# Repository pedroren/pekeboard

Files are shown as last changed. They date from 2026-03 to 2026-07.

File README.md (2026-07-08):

# PeKeboard
PeKeboard and PeKepad

## Idea
The idea was to create a split keyboard without losing some of the occasional keys for miscellaneous or occasional use, like the Function, Media keys and Arrow keys.

I took inspiration (and was about to build) on the Apiaster keyboard (https://github.com/nmunnich/apiaster) and the Soffle variant Souffle (https://github.com/climent/SouffleKeyboard).

So I decided to create a three part keyboard, composed of a pair of split sides, left and right; and a central Macropad, containing the Function and Arrows keys, and a pair of rotary encoders. This central/macropad also doubles as the Dongle, containing a display to show layer and peripherals battery information.

## Tools
- Ergogen
- Kicad
- freerouting

## Folders structure
- layout_keymap:
- pekeboard
- pekepad
- pekepad-v
- zmk-firmware
- rmk_firmware
- release
- kicad

## Subfolders
- cases
- footprints
- pcbs

## Build guide
see build_guide.md

## Todo

## Referenced libraries

- ZMK
- zmk-dongle-display (https://github.com/englmaxi/zmk-dongle-display)
- zmk-feature-status-led (https://github.com/sekigon-gonnoc/zmk-feature-status-led)

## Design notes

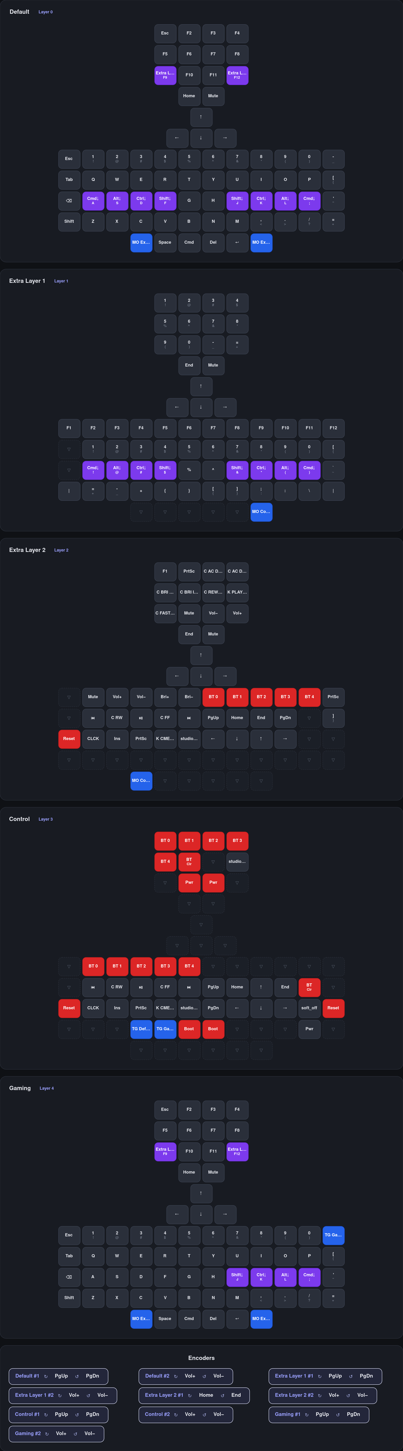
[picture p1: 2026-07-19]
layout_keymap/trio-keymap.png

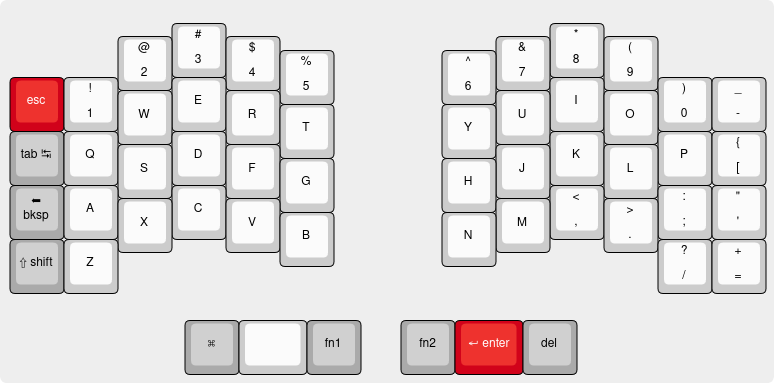
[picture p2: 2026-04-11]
layout_keymap/pekeboard-keyboard-editor-keymap-draft.png

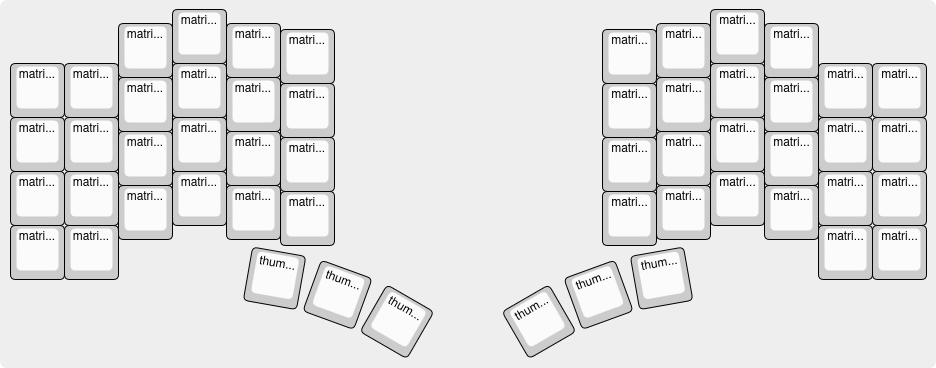
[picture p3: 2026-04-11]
layout_keymap/pekeboard-keyboard-editor-physical.png

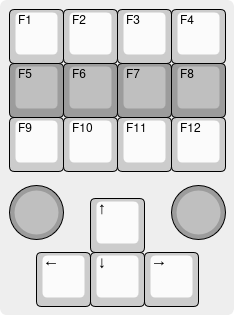
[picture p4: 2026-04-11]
layout_keymap/pekepadv-layout.png

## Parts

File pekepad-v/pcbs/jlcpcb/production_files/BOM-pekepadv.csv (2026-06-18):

Comment | Designator | Footprint | LCSC | Quantity
 | D1,D10,D11,D12,D13,D14,D15,D16,D17,D18,D2,D3,D4,D5,D6,D7,D8,D9 | diode_tht_sod123 | C7420318 | 18

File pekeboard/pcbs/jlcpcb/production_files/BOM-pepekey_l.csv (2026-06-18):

Comment | Designator | Footprint | LCSC | Quantity
 | D1,D10,D11,D12,D13,D14,D15,D16,D17,D18,D19,D2,D20,D21,D22,D23,D24,D25,D26,D27,D3,D4,D5,D6,D7,D8,D9 | diode_tht_sod123 | C7420318 | 27

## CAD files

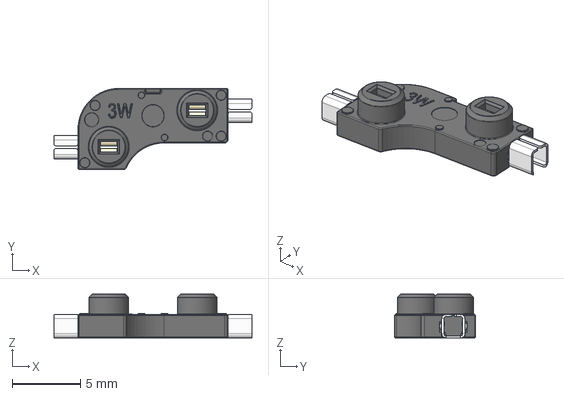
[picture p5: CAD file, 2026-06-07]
kicad/3dmodels/SW_Hotswap_Kailh_MX.stp
14.5 x 5.95 x 3.22 mm

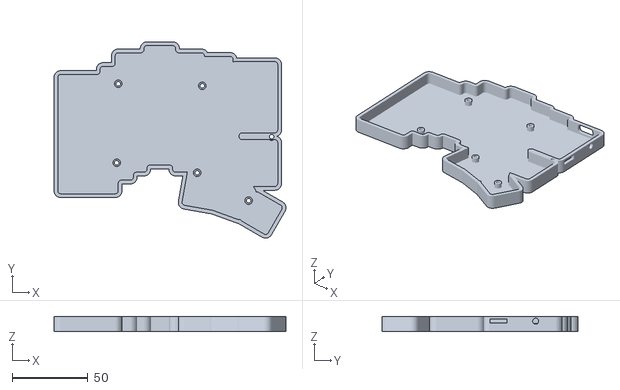
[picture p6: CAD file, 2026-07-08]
pekeboard/cases/case.stl
153.5 x 129.9 x 9.70

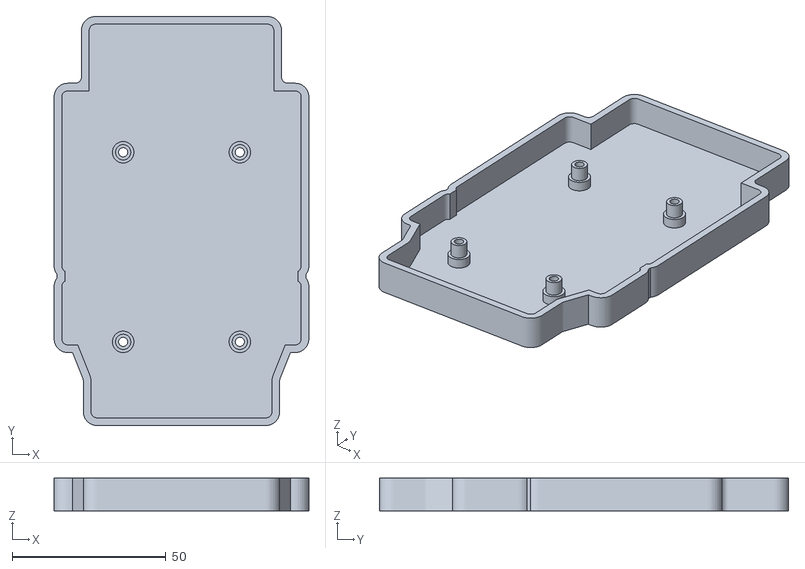
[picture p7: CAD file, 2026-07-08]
pekepad-v/cases/case.stl
83.0 x 133.2 x 10.7

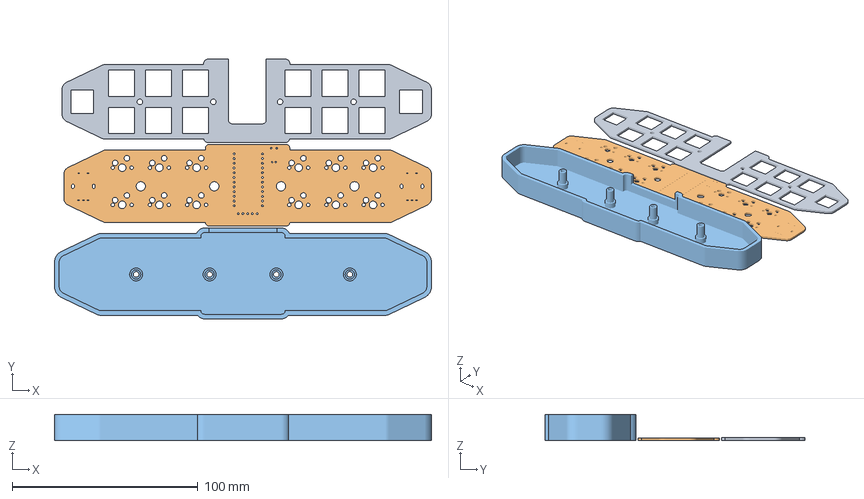
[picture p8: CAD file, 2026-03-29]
pekepad/cases/cases.3mf
202.7 x 139.7 x 14.2 mm
switch_plate.stl
pekepad_pcb.stl
case.stl

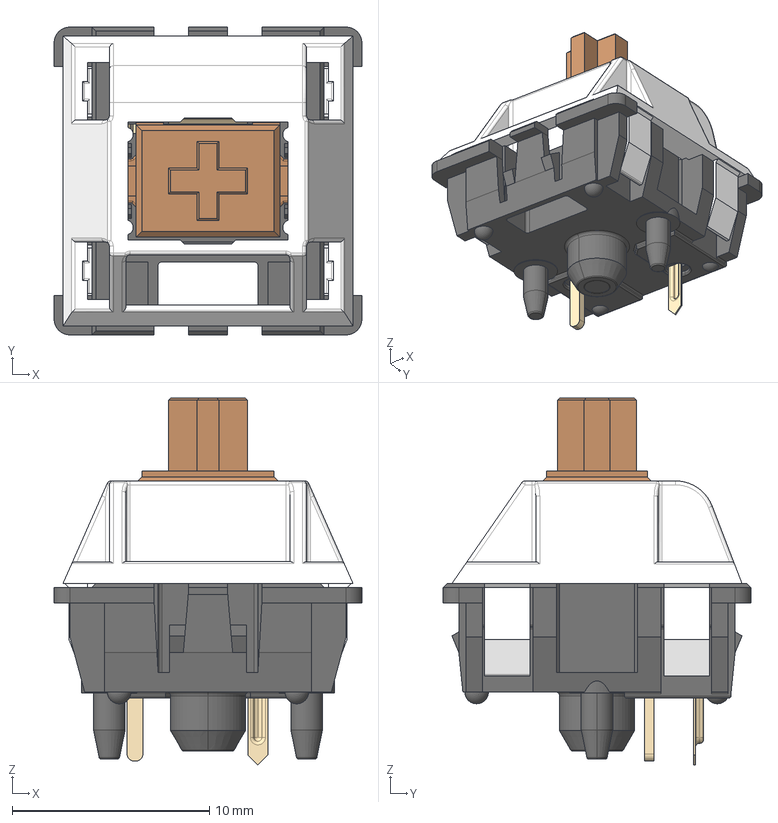
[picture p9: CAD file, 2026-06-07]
kicad/3dmodels/SW_Cherry_MX_PCB.stp
15.6 x 15.6 x 18.6 mm

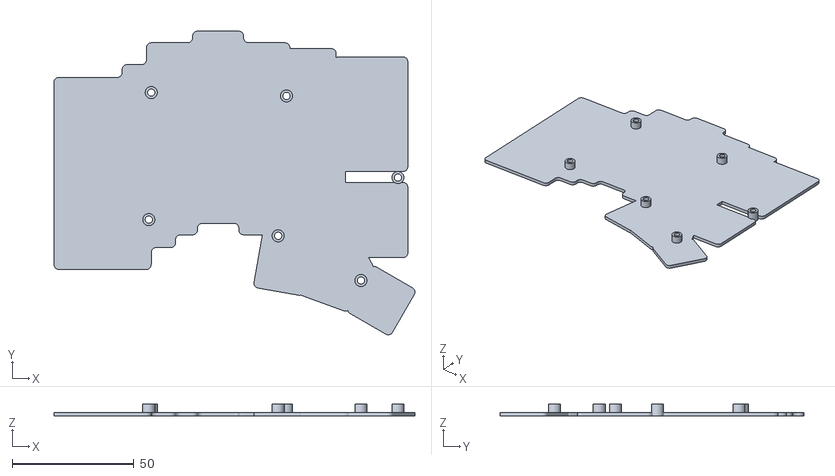
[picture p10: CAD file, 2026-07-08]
pekeboard/cases/sandwich_case.stl
148.5 x 124.9 x 5.10

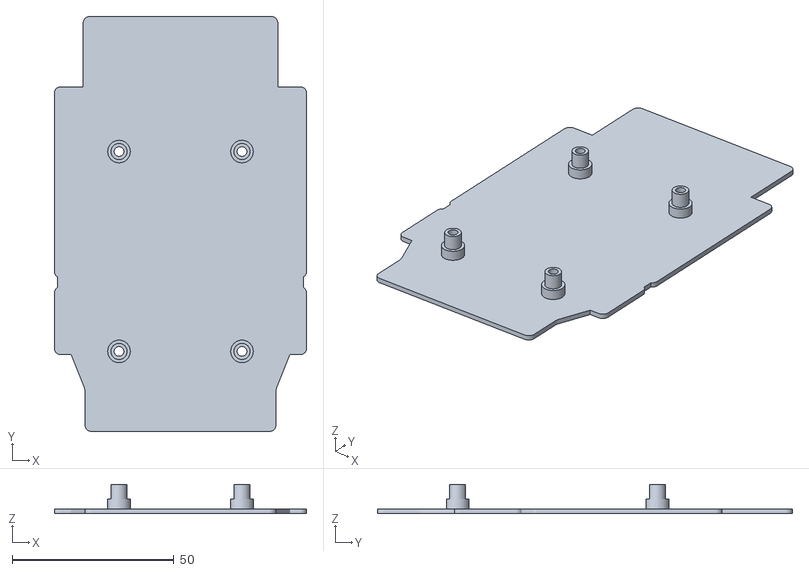
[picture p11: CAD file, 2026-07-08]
pekepad-v/cases/sandwich_case.stl
78.0 x 128.2 x 9.10

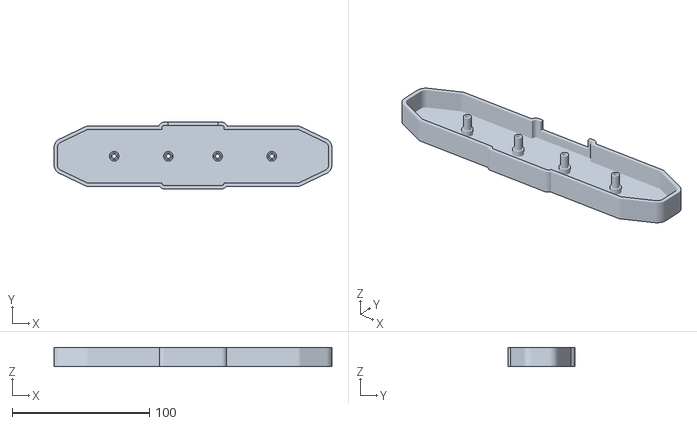
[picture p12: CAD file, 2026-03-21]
pekepad/cases/case.stl
202.7 x 48.9 x 14.2

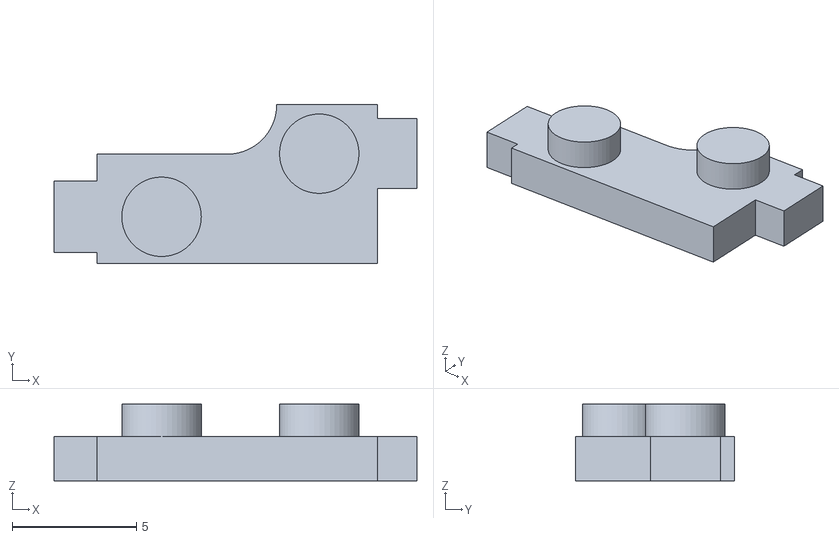
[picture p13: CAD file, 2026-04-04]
kicad/3dmodels/hotswap_socket_mx_style.v0.3.1_2.stl
14.6 x 6.40 x 3.10

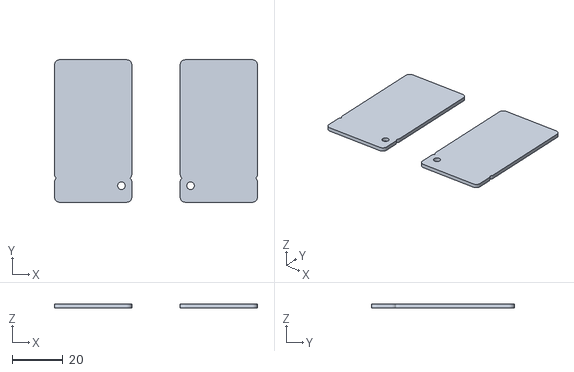
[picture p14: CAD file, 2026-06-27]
pekeboard/cases/controller_cover.stl
79.9 x 56.1 x 1.60

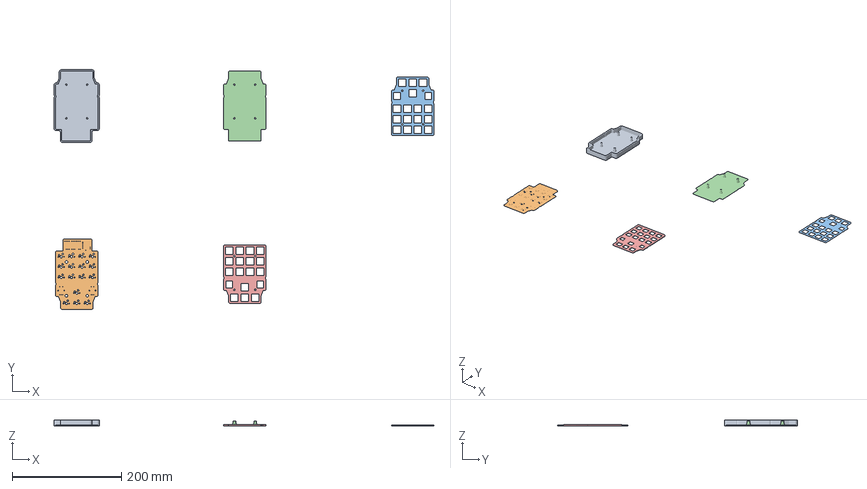
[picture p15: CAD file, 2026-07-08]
pekepad-v/cases/pekepadv-cases.3mf
694.5 x 437.9 x 10.7 mm
case.stl
pcb.stl
switch_plate.stl
sandwich_case.stl
top_gasket.stl

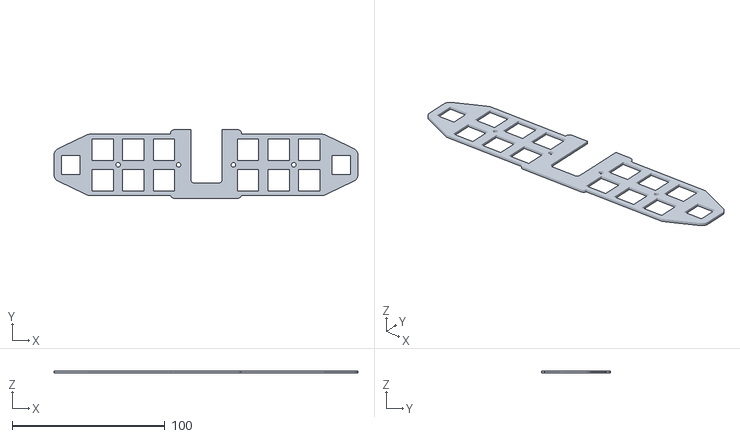
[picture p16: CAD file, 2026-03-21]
pekepad/cases/switch_plate.stl
198.7 x 44.9 x 1.60

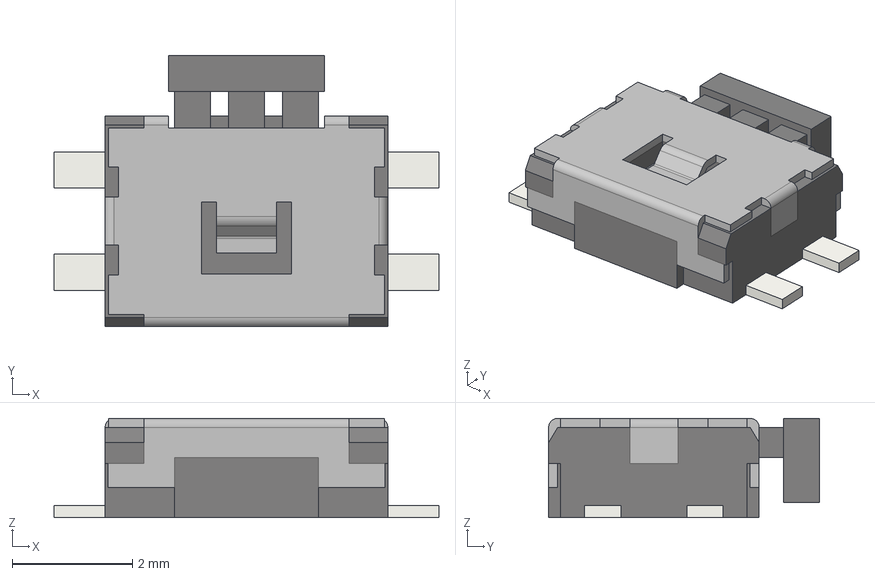
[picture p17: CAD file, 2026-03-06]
kicad/3dmodels/Panasonic_EVQPUJ_EVQPUA.step
6.40 x 4.50 x 1.65 mm

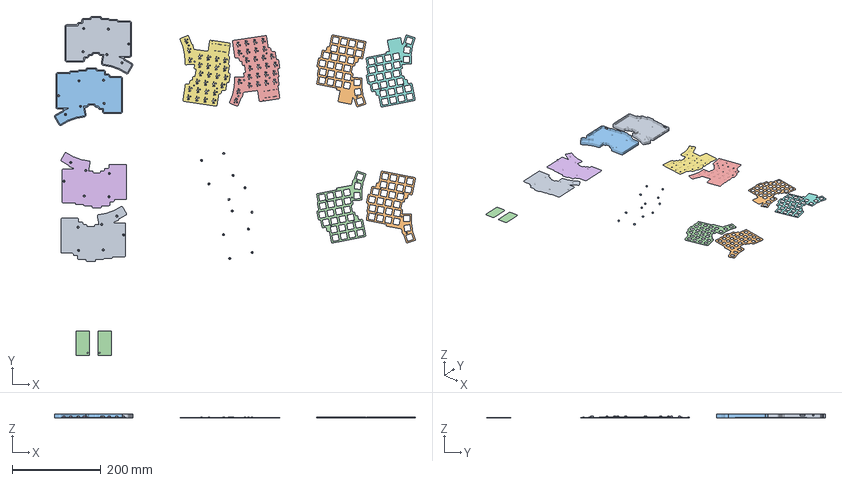
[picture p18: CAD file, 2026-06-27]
pekeboard/cases/pekeboard_cases.3mf
814.3 x 765.7 x 9.70 mm
case_l.stl
top_gasket.stl x 2
plate_support.stl
pcb_l.stl
sandwich_case_l.stl
pcb_r.stl
switch_plate_l.stl
sandwich_case_r.stl
switch_plate_r.stl
case_r.stl
controller_cover.stl

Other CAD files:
pekepad-v/cases/top_gasket.stl
kicad/3dmodels/SW_SPDT_PCM12.step
pekeboard/cases/top_gasket.stl
kicad/3dmodels/D_SOD-123.step
kicad/3dmodels/JST_PH_S2B-PH-K_1x02_P2.00mm_Horizontal.step
pekeboard/cases/pcb.stl
pekeboard/cases/pcb_l.stl
pekeboard/cases/pcb_r.stl
pekeboard/cases/plate_support.stl
pekeboard/cases/switch_plate.stl
pekepad-v/cases/pcb.stl
pekepad-v/cases/switch_plate.stl
pekepad/cases/pekepad_pcb.stl

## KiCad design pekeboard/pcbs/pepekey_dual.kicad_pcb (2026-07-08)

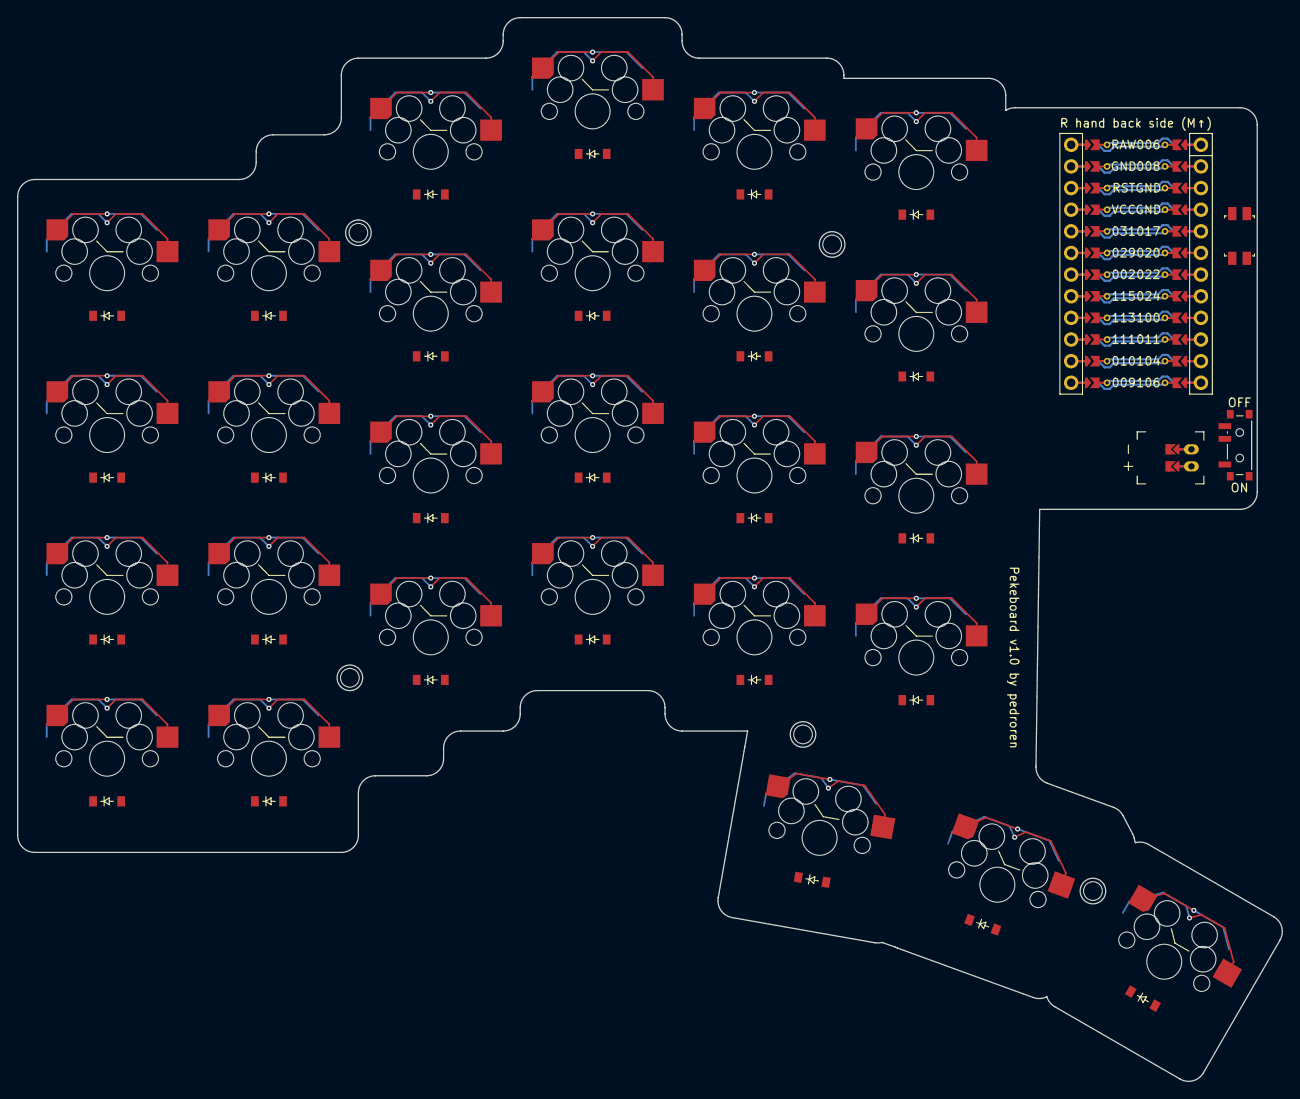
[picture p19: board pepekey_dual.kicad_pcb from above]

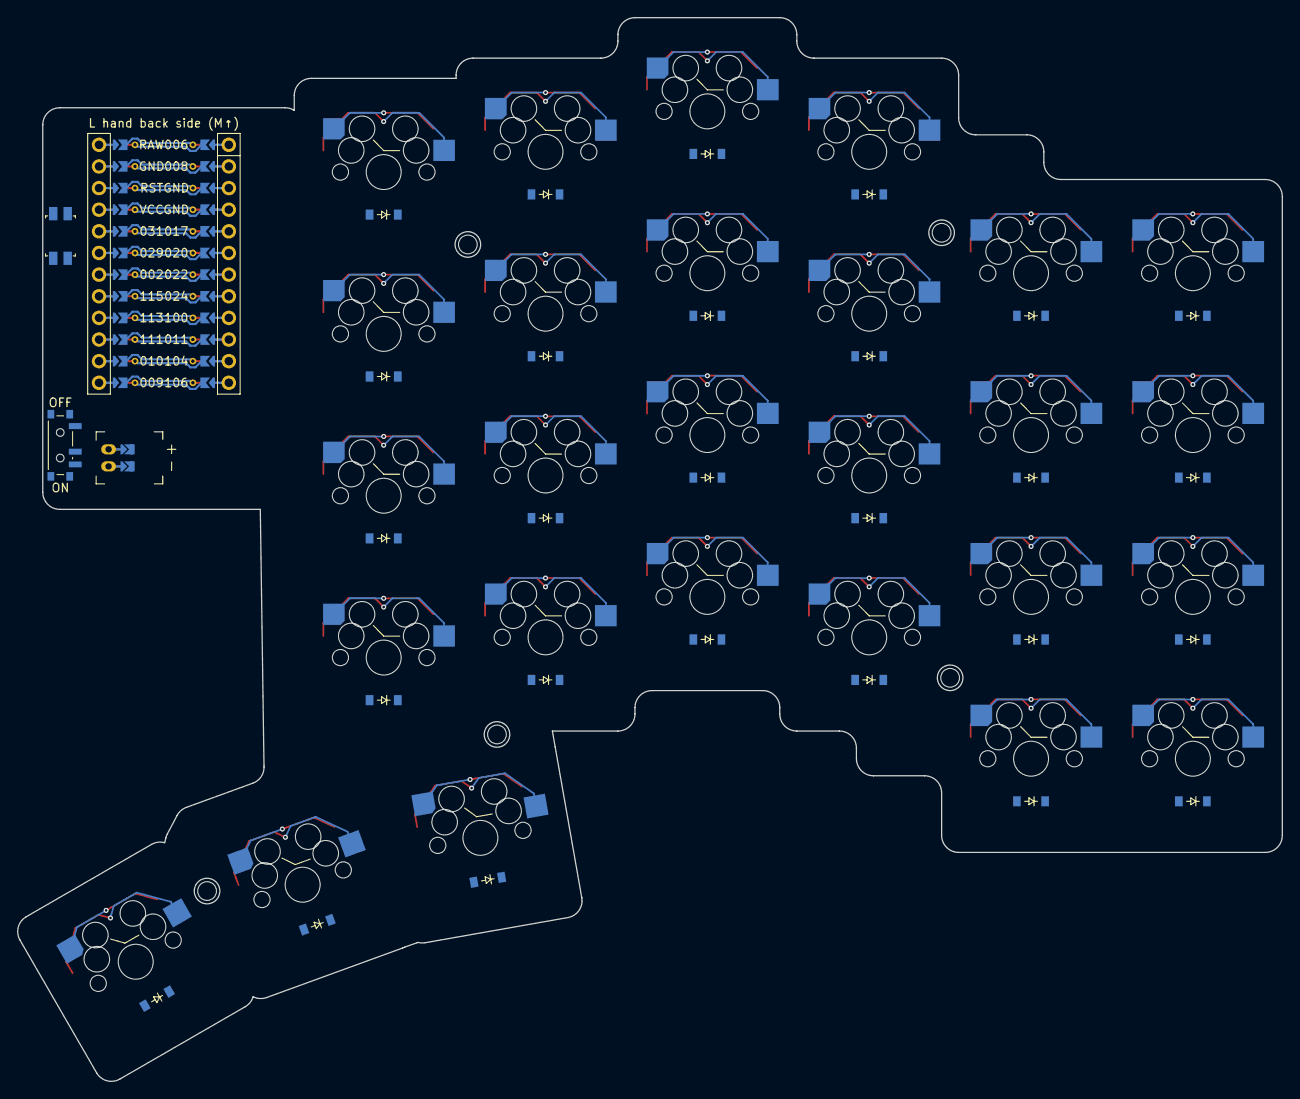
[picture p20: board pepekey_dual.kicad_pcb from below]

Board: 2 copper layers, 148.5 x 124.9 mm, 63 parts (27 on the bottom side), 45 nets.

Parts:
D1, D2, D3, D4, D5, D6, D7, D8, D9, D10, D11, D12, D13, D14, D15, D16, D17, D18, D19, D20, D21, D22, D23, D24, D25, D26, D27: diode_tht_sod123
JST1: battery_connector_jst_ph_2
MCU1: mcu_nice_nano
MH1, MH2, MH3, MH4, MH5: mounting_hole_npth
PWR1: power_switch_smd_side
RST1: reset_switch_smd_side
S1, S2, S3, S4, S5, S6, S7, S8, S9, S10, S11, S12, S13, S14, S15, S16, S17, S18, S19, S20, S21, S22, S23, S24, S25, S26, S27: switch_mx

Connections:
BAT_P: JST1.1, PWR1.1, PWR1.3
GND: JST1.2, MCU1.103, MCU1.104, MCU1.123, RST1.1, RST1.3
JST1_1: JST1.11, JST1.21, JST1.31
JST1_2: JST1.12, JST1.22, JST1.32
P002: D3.1, D7.1, D11.1, D15.1, D19.1, D23.1, MCU1.118
P008: MCU1.102, S1.1, S2.1, S3.1, S4.1
P011: MCU1.110, S17.1, S18.1, S19.1, S20.1, S25.1
P022: MCU1.107, S5.1, S6.1, S7.1, S8.1
P024: MCU1.108, S9.1, S10.1, S11.1, S12.1
P029: D2.1, D6.1, D10.1, D14.1, D18.1, D22.1, MCU1.119
P031: D1.1, D5.1, D9.1, D13.1, D17.1, D21.1, MCU1.120
P100: MCU1.109, S13.1, S14.1, S15.1, S16.1
P106: MCU1.112, S21.1, S22.1, S23.1, S24.1, S26.1
P111: MCU1.115, S27.1
P113: D25.1, D26.1, D27.1, MCU1.116
P115: D4.1, D8.1, D12.1, D16.1, D20.1, D24.1, MCU1.117
RAW: MCU1.124, PWR1.2
RST: MCU1.122, RST1.2, RST1.4
index_bottom: D17.2, S17.2
index_home: D18.2, S18.2
index_num: D20.2, S20.2
index_top: D19.2, S19.2
inner_bottom: D21.2, S21.2
inner_home: D22.2, S22.2
inner_num: D24.2, S24.2
inner_thumbrow: D27.2, S27.2
inner_top: D23.2, S23.2
middle_bottom: D13.2, S13.2
middle_home: D14.2, S14.2
middle_num: D16.2, S16.2
middle_thumbrow: D26.2, S26.2
middle_top: D15.2, S15.2
outer_bottom: D1.2, S1.2
outer_home: D2.2, S2.2
outer_num: D4.2, S4.2
outer_thumbrow: D25.2, S25.2
outer_top: D3.2, S3.2
pinky_bottom: D5.2, S5.2
pinky_home: D6.2, S6.2
pinky_num: D8.2, S8.2
pinky_top: D7.2, S7.2
ring_bottom: D9.2, S9.2
ring_home: D10.2, S10.2
ring_num: D12.2, S12.2
ring_top: D11.2, S11.2

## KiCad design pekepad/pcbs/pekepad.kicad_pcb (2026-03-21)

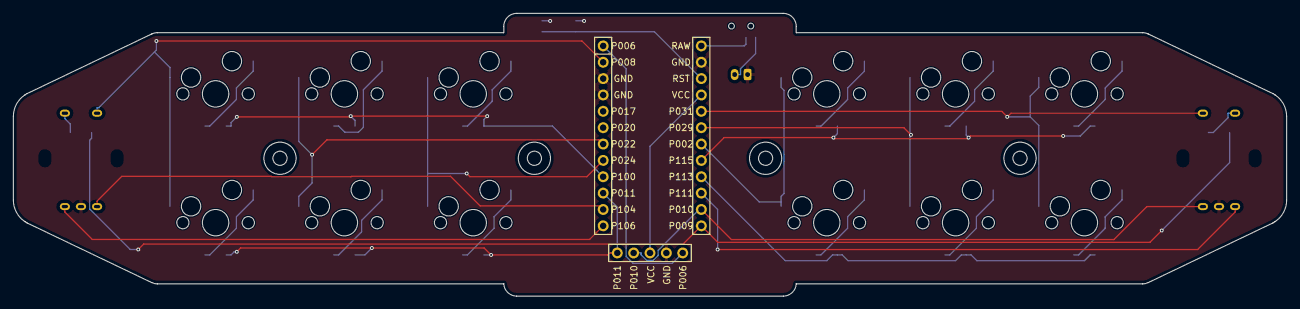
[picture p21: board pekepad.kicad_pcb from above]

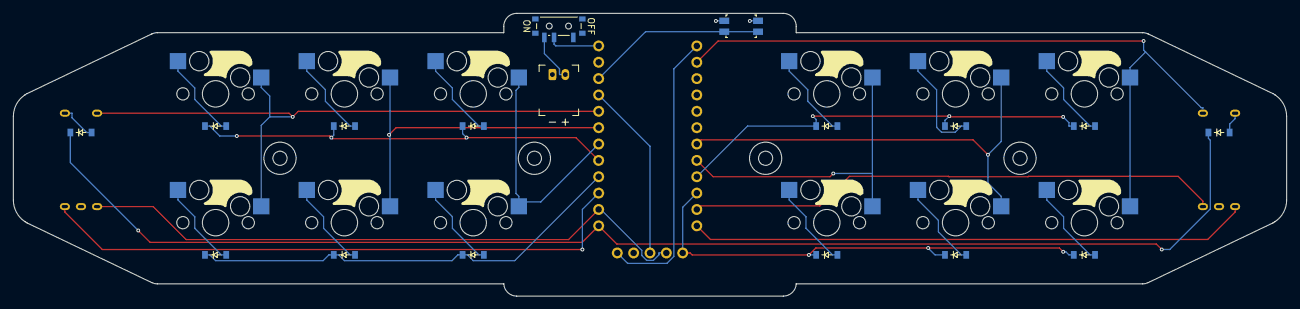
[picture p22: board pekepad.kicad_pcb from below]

Board: 2 copper layers, 197.7 x 43.9 mm, 37 parts (29 on the bottom side), 35 nets.

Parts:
D1, D2, D3, D4, D5, D6, D7, D8, D9, D10, D11, D12, D13, D14: diode_tht_sod123
DISP1: display_nice_view
JST1: battery_connector_jst_ph_2
MCU1: mcu_nice_nano
MH1, MH2, MH3, MH4: mounting_hole_npth
PWR1: power_switch_smd_side
RE1, RE2: rotary_encoder_ec11_ec12
RST1: reset_switch_smd_side
S1, S2, S3, S4, S5, S6, S7, S8, S9, S10, S11, S12: switch_mx

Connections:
BAT_P: JST1.2, PWR1.3
GND: DISP1.4, JST1.1, MCU1.2, MCU1.21, MCU1.22, RE1.B, RE2.B, RST1.1, RST1.3
P002: MCU1.7, S11.1, S12.1
P006: DISP1.5, MCU1.24
P008: MCU1.23, RE1.S2, S1.1, S2.1
P009: D13.1, D14.1, MCU1.12
P010: DISP1.2, MCU1.11, RE2.C
P011: D1.1, D3.1, D5.1, DISP1.1, MCU1.15
P022: MCU1.18, S3.1, S4.1
P024: MCU1.17, S5.1, S6.1
P029: MCU1.6, S9.1, S10.1
P031: MCU1.5, RE2.S1, S7.1, S8.1
P100: D2.1, D4.1, D6.1, MCU1.16
P104: MCU1.14, RE1.A
P106: MCU1.13, RE1.C
P111: MCU1.10, RE2.A
P113: D7.1, D9.1, D11.1, MCU1.9
P115: D8.1, D10.1, D12.1, MCU1.8
RAW: MCU1.1, PWR1.2
RST: MCU1.3, RST1.2, RST1.4
VCC: DISP1.3, MCU1.4
enccol_encrow: D13.2, RE1.S1
inner_bottom: D5.2, S5.2
inner_top: D6.2, S6.2
middle_bottom: D3.2, S3.2
middle_top: D4.2, S4.2
mirror_enccol_encrow: D14.2, RE2.S2
mirror_inner_bottom: D11.2, S11.2
mirror_inner_top: D12.2, S12.2
mirror_middle_bottom: D9.2, S9.2
mirror_middle_top: D10.2, S10.2
mirror_outer_bottom: D7.2, S7.2
mirror_outer_top: D8.2, S8.2
outer_bottom: D1.2, S1.2
outer_top: D2.2, S2.2

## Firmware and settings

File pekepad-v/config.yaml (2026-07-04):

meta:
  name: pepepad-v
  version: 1.0
  engine: 4.1.0
  author: pedroren
units:
  kx: u
  ky: u
  p: 0
  # padding for outer keys
  px: 2
  kpx: kx+px
  py: 2
  kpy: ky+py
  # components size
  mcu_y: 34.1
  mcu_x: 18.3
  mcu_d: 3.3+12 # mcu+sockets
  enc_x: 11.7
  enc_y: 12
  enc_d: 11.5
  batt_x: 18
  batt_y: 32
  batt_d: 6.5 
  # Defaults to M2 Screws
  screw_size: 1.5
  standoff_size: 2.5
  # Case
  case_d: 1.5
  pcb_d: 1.6
  plate_pcb_gap: 3
  bottom_pcb_gap: 3
  usb_access_x: 13
  usb_access_d: 6
  case_y: case_d+bottom_pcb_gap+pcb_d+plate_pcb_gap+pcb_d
points:
  zones:
    matrix:
      anchor:
        shift: [100, -120] #kicad
      key:
        padding: ky+p
        spread: kx+p
        tags: mx_key
      columns:
        left-outer:
          key.column_net: P031 #P008
        left-inner:
          key.column_net: P029 #P022
        right-inner:
          key.column_net: P002 #P024
        right-outer:
          key.column_net: P115 #P100
      rows:
        bottom:
          row_net: P011 #P104
        middle:
          row_net: P100 #P106
        top:
          row_net: P024 #P031
    arrow_cluster:
      key:
        padding: ky+p
        spread: kx+p
        tags: mx_key
      anchor:
        ref: matrix_left-outer_bottom
        shift: [.5kx, -2.5ky]
      columns:
        left:
          key.column_net: P031 #P008
          rows.top.skip: true
        middle:
          key.column_net: P029 #P022
        right:
          rows.top.skip: true
          key.column_net: P002 #P024
      rows:
        bottom:        
          row_net: P009 #P029    
        top:
          row_net: P104
    encoders:
      key.tags: [encoder]
      anchor:
        ref: matrix_left-outer_bottom
        shift: [0, -1.25ky]
      columns:
        left:
          key:
            pin_a: P022 #P115
            pin_c: P008 #P113
            column_net: P031 #P008
        right:
          key:
            shift: [2kx, 0]
            pin_a: P110 #P111
            pin_c: P106
            column_net: P115 #P100
      rows:
        enc-row:
          row_net: P104 #P002
    mount1:
      key.tags: [mount]
      anchor:
        ref.aggregate.parts: [
          matrix_left-outer_top,  
          matrix_left-inner_top ,
          matrix_left-inner_middle,
          matrix_left-outer_middle]
    mount2:
      key.tags: [mount]
      anchor:
        ref.aggregate.parts: [
          matrix_right-outer_top,  
          matrix_right-inner_top ,
          matrix_right-inner_middle,
          matrix_right-outer_middle]
        shift: [0,0]
    mount3:
      key.tags: [mount]
      anchor:
        ref: encoders_left_enc-row
        shift: [.5kx, -.5ky]
    mount4:
      key.tags: [mount]
      anchor:
        ref: encoders_right_enc-row
        shift: [-.5kx, -.5ky]        
    controller:
      key.tags: [mcu]
      anchor:        
        ref.aggregate.parts: [          
          matrix_right-inner_top ,
          matrix_left-inner_top]
        shift: [-12,1ky+2]
    reset_button:
      key.tags: [reset_btn]          
      anchor: 
        - ref: controller
          shift: [.75mcu_y+14, 5]
    power_button:
      key.tags: [power_btn]          
      anchor: 
        - ref: controller
          shift: [.75mcu_y+14, -5]                  
outlines:
  keys_socket:
    - what: rectangle
      where: [mx_key]
      size: [14, 14]
  keycaps:
    - what: rectangle 
      where: [mx_key]
      size: [kx, ky] 
      corner: 1
  switches:
    - what: rectangle
      where: [mx_key]
      size: 14
  keywell:
    - what: rectangle 
      where: [mx_key, encoder]
      size: [kpx, kpy] 
      corner: 2
      fillet: 4
      bound: true 
  controller:
    - what: rectangle
      where: [mcu]
      size: [mcu_x, mcu_y]           
  controller_area:
    - what: rectangle
      where: [mcu]        
      size: [1.5mcu_x-3, 1.5mcu_y+9]
      corner: 2      
      adjust:
        shift: [12, -1]      
        rotate: 90
  encoders:
    - what: rectangle
      where: [encoder]
      size: [enc_x+.5, enc_y+.5]                   
  arrows_patch:
    - what: polygon    
      operation: stack
      fillet: 2
      points:
          - ref: matrix_left-outer_bottom
            shift: [-.5kx, 0]      
          - ref: encoders_left_enc-row
            shift: [-.5kx, 0]        
          - ref: arrow_cluster_left_bottom
            shift: [-.5kx, 0]          
          - ref: arrow_cluster_right_bottom
            shift: [.5kx, 0]            
          - ref: encoders_right_enc-row
            shift: [.5kx, 0]      
          - ref: matrix_right-outer_bottom
            shift: [.5kx, 0]                    
  screw_holes:
    - what: circle
      radius: screw_size    
      where: [mount]
  mounting_holes:
    - what: circle
      radius: standoff_size    
      where: [mount]
  pcb_support:
    - what: outline
      name: mounting_holes
      expand: 1
  plate_outline:
    - keywell
    - name: arrows_patch
      operation: add
      joints: beveled
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

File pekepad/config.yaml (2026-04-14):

meta:
  name: pekepad
  version: 0.0.1
  engine: 4.1.0
  author: pedroren
units:
  k: u
  p: 1
  px: 4
  py: 2
  kpx: k+px
  kpy: k+py
  # components size
  mcu_y: 34.1
  mcu_x: 18.3
  mcu_d: 3.3+12 # mcu+sockets
  enc_x: 11.7
  enc_y: 12
  enc_d: 11.5
  batt_x: 12
  batt_y: 30
  batt_d: 4  
  # Defaults to M2 Screws
  screw_size: 1.5
  standoff_size: 2.5
  # Case
  case_d: 2
  pcb_d: 1.6
  plate_pcb_gap: 5
  bottom_pcb_gap: 4
  case_y: case_d+bottom_pcb_gap+pcb_d+plate_pcb_gap+pcb_d

points:
  zones:
    matrix:
      anchor:
        shift: [100, -120]
      key:
        padding: p+u
        spread: p+u
        tags: [switch]
      columns:
        outer:
          key.column_net: P008
          key.mirror.column_net: P031
        middle:
          key.column_net: P022
          key.mirror.column_net: P029
        inner:
          key.column_net: P024
          key.mirror.column_net: P002
      rows:
        bottom:
          row_net: P011
          mirror.row_net: P113
        top:
          row_net: P100
          mirror.row_net: P115
    encoders:
      key:
        padding: p+u
        spread: p+u
        tags: [encoder]
      anchor:
        ref.aggregate.parts: [matrix_outer_top,  matrix_outer_bottom]
        shift: [-1.1k, 0]
      columns:
        enccol:
          key.pin_a: P104
          key.pin_c: P106
          key.mirror.pin_a: P111
          key.mirror.pin_c: P010
          key.column_net: P008
          key.mirror.column_net: P031
      rows:
        encrow:
          row_net: P009
          mirror.row_net: P009
    mcu:
      key.tags: [mcu]
      key.asym: source
      anchor:
        ref.aggregate.parts: [matrix_inner_top, matrix_inner_bottom]
        shift: [.5k+mcu_x, .25k]
    mount1:
      key.tags: [mount]
      anchor:
        ref.aggregate.parts: [matrix_outer_top,  matrix_outer_bottom, matrix_middle_top,  matrix_middle_bottom]
    mount:
      key.tags: [mount]
      anchor:
        ref.aggregate.parts: [matrix_inner_top, matrix_inner_bottom]
        shift: [.5k,0]
  rotate: 0
  mirror: &mirror
    ref: matrix_inner_top
    distance: 3mcu_x
outlines:
  raw:
    - what: rectangle
      where: [switch,encoder,mcu]
      size: [k, k]
  keys_socket:
    - what: rectangle
      where: [switch]
      size: [14, 14]
  keys:
    - what: rectangle
      where: [switch]
      size: [k-0.5, k-0.5]
  keys_area:
    - what: rectangle
      where: [switch]
      size: [5+k, 5+k]
      bound: true
      corner: px
  controller_area:
    - what: polygon
      fillet: 2
      points:
        - ref: matrix_inner_top
          shift: [.25k, .5k+3]
        - ref: mirror_matrix_inner_top
          shift: [.25k, .5k+3]
        - ref: mirror_matrix_inner_bottom
          shift: [.25k, -.6k]
        - ref: matrix_inner_bottom
          shift: [.25k, -.6k]
  controller_cutout: 
    - what: rectangle
      where: [mcu]
      adjust:
        shift: [0, 2]
      size: [mcu_x+2, mcu_y+3]
      corner: 2
  battery_area:
    - what: rectangle
      where:
        ref.aggregate.parts: [matrix_inner_top, mirror_matrix_inner_top,matrix_inner_bottom, mirror_matrix_inner_bottom]
      size: [1.5batt_x, batt_y+4]
      corner: 2
  battery_wall:
    - what: outline
      name: battery_area
      expand: case_d
      joints: beveled
  encoder_area:
    - what: rectangle
      where: [encoder]
      size: [2+k, 2+k]
      corner: px
  encoder_socket: #cutout
    - what: rectangle
      where: [encoder]
      size: [enc_x+.5, enc_y+.5]
  usb_access:
    - what: rectangle
      where:
        ref.aggregate.parts: [matrix_inner_top, mirror_matrix_inner_top]
        shift: [0, 0.5k+1]
      size: [2mcu_x, case_y]
  baseboard:
    - what: polygon
      operation: stack
      fillet: 2
      points:
        - ref: matrix_outer_top
          shift: [-0.5k, 0.5k]
        - ref: matrix_middle_top
          shift: [0, 0.5k]
        - ref: matrix_inner_top
          shift: [0, 0.5k]
        - ref: mirror_matrix_inner_top
          shift: [0, 0.5k]
        - ref: mirror_matrix_middle_top
          shift: [0, 0.5k]
        - ref: mirror_matrix_outer_top
          shift: [-0.5k, 0.5k]
        - ref: mirror_encoders_enccol_encrow
          shift: [-0.5k, 0.5k]
        - ref: mirror_encoders_enccol_encrow
          shift: [-0.5k, -0.5k]
        - ref: mirror_matrix_outer_bottom
          shift: [-0.5k, -0.5k]
        - ref: mirror_matrix_inner_bottom
          shift: [0, -0.5k]
        - ref: matrix_inner_bottom
          shift: [0, -0.5k]
        - ref: matrix_outer_bottom
          shift: [-0.5k, -0.5k]
        - ref: encoders_enccol_encrow
          shift: [-0.5k, -0.5k]
        - ref: encoders_enccol_encrow
          shift: [-0.5k, 0.5k]
  mounting:
    - what: circle
      radius: screw_size
      where: [mount]
  standoff:
    - what: circle
      radius: standoff_size
      where: [mount]
  pcb_support:
    - what: outline
      name: standoff
      expand: 1
  inner_area:
    - baseboard
    - controller_area
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

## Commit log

2026-03-05 batt connector space fix
    [case.stl, pekepad.kicad_pcb, switch_plate.kicad_pcb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]
2026-03-06 Freeing up Pin P1 (SC) for Nice View Adding some 3D models for kicad
    [D_SOD-123.step, JST_PH_S2B-PH-K_1x02_P2.00mm_Horizontal.step, Panasonic_EVQPUJ_EVQPUA.step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]
2026-03-09 Ergogen: Updating assigned pins Ergogen: Renaming pins names to NiceNano Pings RMK: Updating assigned pins RMK: Always clear storage, temporary RMK: Trying to fix vial layout
    [cases.3mf, pekepad.kicad_pcb, switch_plate.kicad_pcb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]
2026-03-09 Ergogen: increasing encoder hole
    [cases.3mf, pekepad.kicad_pcb]
2026-03-11 Inner case verical spacing Cutout for USB, reset and power Switchplate sides support
    [case.stl, cases.3mf, pekepad.kicad_pcb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]
2026-03-11 Adjusting case inner space
    [case.stl, pekepad.kicad_pcb, switch_plate.kicad_pcb]
2026-03-11 More case fixes
    [case.stl, pekepad.kicad_pcb, switch_plate.kicad_pcb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]
2026-03-12 More fixes to the case/pcb/plate
    [case.stl, cases.3mf, pekepad.kicad_pcb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]
2026-03-12 forgot pcb wiring
    [pekepad.kicad_pcb]
2026-03-12 adjusting I2C/SPI pins
    [pekepad.kicad_pcb]
2026-03-15 remove hardcoded ceoloide
    [cases.3mf, pekepad.kicad_pcb, pekepad_pcb.stl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]
2026-03-15 Reorganizing kicad common folder
    [D_SOD-123.step, JST_PH_S2B-PH-K_1x02_P2.00mm_Horizontal.step, Panasonic_EVQPUJ_EVQPUA.step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]
2026-03-15 reorganizing kicad custom footprints
2026-03-15 Missing encoder cutout on plate
    [config.yaml]
2026-03-16 work on keyboard
    [bottom_plate.kicad_pcb, pepekey.kicad_pcb, top_plate.kicad_pcb]
2026-03-17 Fixing macropad plate mcu cutout
    [case.stl, cases.3mf, switch_plate.kicad_pcb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]
2026-03-21 Ajusting plate mcu cutout mcu is now a point of reference
    [case.stl, cases.3mf, pekepad.kicad_pcb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]
2026-03-29 rmk: encoder step fix. zmk firmware.
2026-03-29 encoder fix
2026-04-04 pekeboard cases
    [bottom_plate.kicad_pcb, case.stl, hotswap_socket_mx_style.v0.3.1_2.stl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]
2026-04-05 pekeboard case refinement and cutouts
    [bottom_plate.kicad_pcb, case.stl, pekeboard_cases.3mf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]
2026-04-05 Battery area and cover
    [bottom_plate.kicad_pcb, case.stl, pekeboard_cases.3mf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]
2026-04-05 Fixing keys spacing More case and battery space refinements
    [bottom_plate.kicad_pcb, case.stl, pekeboard_cases.3mf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]
2026-04-05 reducing pcb padding
2026-04-06 Extreme trimming
    [bottom_plate.kicad_pcb, case.stl, pekeboard_cases.3mf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]
2026-04-06 Sandwich style bottom case
    [pekeboard_cases.3mf, sandwich_case.stl]
2026-04-07 Adjusting mounting holes
    [bottom_plate.kicad_pcb, case.stl, pekeboard_cases.3mf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]
2026-04-08 Bump version and enable reversible pcb
    Updated version to 0.1.0 and set reversible pcb parameters to true.
2026-04-09 Fix mounting hole outside PCB
    [bottom_plate.kicad_pcb, pepekey.kicad_pcb, top_plate.kicad_pcb]
2026-04-09 reversible diodes removing fill zone
    [bottom_plate.kicad_pcb, pekeboard_cases.3mf, pepekey.kicad_pcb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]
2026-04-11 Fix pekeboard sandwich case "walls"
    [config.yaml]
2026-04-12 pekepad folder fix
    [arrows_patch.dxf, base_outline.dxf, bottom_plate.kicad_pcb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]
2026-04-14 pekeboard case small adjustments
2026-04-14 Less spread for thumb cluster
    [bottom_plate.kicad_pcb, case.stl, pekeboard_cases.3mf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]
2026-04-14 reorganizing case
    [pekepadv-B_Cu.gbr, pekepadv-B_Mask.gbr, pekepadv-B_Paste.gbr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]
2026-04-14 kicad gitignore
2026-04-14 reorganizing folders
    [arrows_patch.dxf, base_outline.dxf, bottom_plate.kicad_pcb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]
2026-04-14 renaming macropad folder
    [case.stl, cases.3mf, pekepad.kicad_pcb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]
2026-04-15 updating generated files
    [bottom_plate.kicad_pcb, pekeboard_cases.3mf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]
2026-04-15 switchplate fix
    [base_outline.dxf, case.stl, pcb.step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]
2026-04-16 Moving battery connector to Front
    [pekepadv-B_Cu.gbr, pekepadv-B_Mask.gbr, pekepadv-B_Paste.gbr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]
2026-05-12 Removing pcb mounting hole, only screw Adding plate support o-rings
    [case.stl, pekeboard_cases.3mf, plate_support.stl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]
2026-06-07 - Switching to non-reversible pcb left and right sides - Fix invalid pin - 3D model for MX switches
    [SW_Cherry_MX_PCB.stp]
2026-06-07 Adjusting thumbs pin to allow autorouting
2026-06-07 Removing right side for Cases section
    [SW_Hotswap_Kailh_MX.stp, bottom_plate.kicad_pcb, case.stl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]
2026-06-12 pcb label
2026-06-12 submodule ref
    [pepekey_l.kicad_pcb, pepekey_r.kicad_pcb, top_plate.kicad_pcb]
2026-06-18 V1.0 Fabrication sent to JLCPCB
    [BOM-pepekey_l.csv, BOM-pepekey_r.csv, bottom_plate.kicad_pcb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]
2026-06-18 JLCPCB fabrication ready
    [BOM-pekepadv.csv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]
2026-06-18 case adjustment for new PCB dimensions
    [case.stl, pcb_l.stl, pcb_r.stl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]
2026-06-26 pekeboard: Reducing battery cover, adding top gasket
    [pekeboard_cases.3mf, switch_plate.stl, top_gasket.stl]
2026-06-27 restoring reversible PCB option
    [pepekey_dual.kicad_pcb]
2026-07-04 pekepad-v top_gasket
    [pekepadv-cases.3mf, top_gasket.stl]
2026-07-08 cleanup and built zmk firmware files
    [bottom_plate.kicad_pcb, case.stl, pekepadv-cases.3mf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]
2026-07-08 Apply updated .gitignore and untrack folders
    [arrows_patch.dxf, base_outline.dxf, controller.dxf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]

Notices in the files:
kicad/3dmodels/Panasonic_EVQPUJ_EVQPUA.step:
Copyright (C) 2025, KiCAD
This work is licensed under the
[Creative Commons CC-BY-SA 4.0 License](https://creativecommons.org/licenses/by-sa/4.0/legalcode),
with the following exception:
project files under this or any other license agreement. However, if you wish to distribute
